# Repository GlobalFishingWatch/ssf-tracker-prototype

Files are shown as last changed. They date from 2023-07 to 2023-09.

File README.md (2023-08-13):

# ssf-tracker-prototype
Prototyping a low-cost low-power GPS tracker for small scale fishing vessels

## Project Goal
Develop a simple, robust, low cost hardware device that can be used for location tracking
for small-scale fishing vessels in a global context.

Pilot test the device and develop a plan to scale it out to >100k vessels.

GFW will develop cloud back end, web and app-based UX tools for interacting with the data, probably in house but potentially with a partner.

Data from the small vessels will be combined with other data GFW collects for larger vessels to provide a richer picture of what is happening.

[Project Background](background.md)

[Hardware requirements](requirements.md)

[Device Designs](design/README.md)

Diagrams in markdown files are formatted using [Mermaid](https://mermaid.js.org/)

## Developing

```console
git clone https://github.com/GlobalFishingWatch/ssf-tracker-prototype
cd ssf-tracker-prototype
```

See [README.md](controller/README.md) for more on developing the controller micropython code

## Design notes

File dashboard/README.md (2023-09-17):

# SSF Tracker Device Dashboard

This app connects to a local instance of the tracker device using Bluetooth LE (BLE).

This will only work in Chrome, and you need to enable BLE in Chrome before it will be able to connect.

To enable BLE in the browser, navigate to `chrome://flags/experimental-web-platform-features` and set it to `Enabled`

Then open index.html and you should be able to connect to the device and control it

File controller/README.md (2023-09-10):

# Micro Controller

The controller runs on an arduino ESP32 running micropython

## Set up the local dev environment
We use micropython to run the code in the arduino, nut we use standard python for development and testing because I haven't figured out how to use unittest properly in micropython.  Ideally we would run all the unitest in micropython on the dev machine so taht we know everything is the same as it will be on the arduino. 

### Python setup for osx - create a python environment if you don't aleady have one
```
conda create -n py311 python=3.11.4 
conda avtivate py311
```

### Create a python virtualenv
```console
pip install virtualenv
cd controller
virtualenv venv
source venv/bin/activate
pip install -r requirements-dev.txt 
```

### Run the unit tests
```console
python app/test.py
```

### install micropython on the ESP32-S3 board

Using [this guide](https://micropython.org/download/GENERIC_S3/)

```
pip install esptool

esptool.py --chip esp32-S3 --port /dev/tty.usbmodem101 erase_flash
esptool.py --chip esp32s3 --port /dev/tty.usbmodem101 write_flash -z 0 ~/Downloads/GENERIC_S3-20230426-v1.20.0.bin 
```

### Install micropython on the dev machine
On OSX, install micropython from source
https://docs.micropython.org/en/latest/develop/gettingstarted.html#building-the-unix-port-of-micropython

```console
git clone https://github.com/micropython/micropython
cd micropython/mpy-cross
make
cd ../ports/unix
make submodules
make
./micropython
```

Now install some packages from micropython-lib
```console
micropython -m mip install unittest
micropython -m mip install tempfile
micropython -m mip install logging
micropython -m mip install shutil
micropython -m mip install ujson
micropython -m mip install collecttions-deque
micropython -m mip install copy
```

Now you should be able to run the unit tests with micropython
```console
micropython app/test.py
```
 
### Install packages to the esp32 device
Use mpremote - [documentation](https://docs.micropython.org/en/latest/reference/mpremote.html)
```console
pip install mpremote

mpremote fs mkdir lib
mpremote mip install $(cat requirements-micropython-dev.txt)
```

### Copy files to the esp32 device
#### Copy with mpremote
```console
mpremote cp $(ls app/*.py) :
```
Note that this seems to fail intermittently, so here's an alternative way

#### Copy files with mpy-upload

Use mpy-upload - [documentation](https://github.com/nickzoic/mpy-utils)

First you need to find the port (mpremote finds it auto-magically)
```console
ls /dev/cu*
```

Then use the usb port to copy all the files
```console
pip install mpy-utils

mpy-upload --port /dev/cu.usbmodem5629254 app/*.py
```

### Open a REPL on the device so you can run things

```console
mpremote repl
```
You may need to hit ctrl-B to get a the `>>>` prompt

### Run the unit tests in the REPL
```python
>>> from test import run_all_tests_esp32
>>> run_all_tests_esp32()
```

### Now finally, run the App!
From the repl
```python
>>> import main
>>> main.app.run()
```
ctrl-c to break

## SOME RANDOM NOTES BELOW

How to create a virtual env using micropython (not working?)
```
ln -s /Users/paul/github/micropython/ports/unix/build-standard/micropython /usr/local/bin/micropython
micropython -m mip install venv
source venv-mpy/bin/activate 
```

### Using Thonny IDE to run python code on the ESP hardware

### Monitor the serial port directly from OSX

1. Connect the usb cable to the COM port (not the USB port)

2. find the device name
```
ls /dev/cu*
```
3. should look something like this
```
/dev/cu.usbmodem56292549741
```
4. then connect with screen
```
screen /dev/cu.usbmodem56292549741 115200
```
5. To exit screen, do ctrl-a and then k to kill the session

### set up mpy-utils for direct file system access
github: https://github.com/nickzoic/mpy-utils
```
pip install mpy-utils
```

Use mpremote
```console
pip install mpremote
```
To open a shell to the REPL. You may need to hit ctrl-B to get the prompt
```console
mpremote repl
```
It should auto-discover the usb port

To copy files from the host to the device
```console
mpremote cp test.py :tesy.py
mpremote cp test/*.py :
```

List files on the device
```console
mpremote fs ls
```

Install modules using mip onto the device
```console
mpremote fs mkdir lib
mpremote mip install logging
```

#### Copy files with mpy-upload
DEPRECATED - using `mpremote cp` is better

Use mpy-upload - [documentation](https://github.com/nickzoic/mpy-utils)

First you need to find the port (mpremote finds it auto-magically)
```console
ls /dev/cu*
```

Then use the usb port to copy all the files
```console
pip install mpy-utils

mpy-upload --port /dev/cu.usbmodem5629254 app/*.py
```

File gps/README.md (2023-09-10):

# GPS Testing

In prior experiments, we have found that the the biggest source of power use is getting a GPS fix.   

We want to try to measure how much power we will need to acquire GPS fixes over time

### Test Questions
1. How long on average does it take to get a GPS fix over a long series of wake/fix/sleep cycles
2. How much power do we consume while getting a fix
3. How do things change when we change the fix interval

### Test setup with the Adafruit Ultimate GPS
Using an arduino feather esp32 for the conroller and AdaFruit Ultimate GPS breakout 

### Test 1

* Power the GPS from the controller 3V3
* Install a button battery in the GPS
* Use the external antenna in an outdoor location with a clear view of the sky
* Set up a sleep/wake cycle in the controller, using deepsleep
* On sleep, disable the GPS with the `EN` pin
* On wake, enable the GPS, wait for it to get a fix
* After the GPS gets a fix, disable it with the `EN` in and send the controller to sleep

#### Measures
* Log the fixed location (so we can check consistency across multiple readings)
* Log the time from wake to fix
* Compute the average and cumulative time the controller spends awake
* Measure total power consumption of the entire system during wake and sleep
* Measure the power consumption of just the GPS with EN on and off

Run this test for a couple of days and see what the timings look like

#### Test 2

* Same setup as test 1, but try to put the controller into light sleep while you wait for the GPS to get a fix. 
* See if there is a way to wake the controller using the `FIX` pin perhaps?
* Or just sleep for a short period like 500ms and then wake and check
* Measure to see if this extra complexity reduces overall power consumption

#### Test 3

* Try using the built-in LOCUS logger in low power mode and let the controller deepsleep for a longer time, waking up to collect the logged positions once per hour

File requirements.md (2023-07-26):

# Device requirements

## Desired hardware characteristics

* Total 5-year cost of ownership < $500.  This includes
  * up front hardware cost
  * hardware replacement cost, depending on failure rate
  * data communications service
* Coverage: global between latitude -50 and +50
* Data collected: lat/lon, time, speed
* Data logging frequency: 5-10 miuntes
* Data transmission frequency: not longer than 4 hours, otherwise as often as power permits
* Hardware package:
  * As simple as possible.
  * Ideally it is permanently sealed - needs to stand up to rough treatment and maritme conditions
  * Only needs one indicator light
  * Wireless charging and configuration (BLE?)
  * Only needs one button (for activation & SOS)
  * Does not have to be pretty
* Power
  * Internal rechargeable battery
  * Can have solar power (but don't count on optimal placement for captureing solar.  Assume 10% of rated solar caapcity)
* Weight and size
  * Will be attached to the structure of the boat (probably with zip ties)
  * Can be heavy and bulky, but cannot have anything sticking out that can get broken off
* Trial locations
  * Indonesia (with GFW staff)
  * Philippines (with Rare staff)
* Intellectual property license
  * Generally, everything we do is open source, so fully open source hardware and software design would be great
  * GFW publishes all our software under Apache 2.0 and data under CC-BY-NC

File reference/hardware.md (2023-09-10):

# Hardware Reference

## Microcontrollers
### ESP32-S3 DevKit C
To flash, press and hold `reset` and `boot,` then release `reset` and the relase `boot`
Be sure also to connect to the `USB` usb-c port and not the `Com` port

#### Docs
* [Espressif](https://docs.espressif.com/projects/esp-idf/en/latest/esp32s3/hw-reference/esp32s3/user-guide-devkitc-1.html)
* [Amazon](https://www.amazon.com/gp/product/B0B6HT7V7P/ref=ppx_yo_dt_b_asin_title_o05_s00?ie=UTF8&psc=1)
* [Build and flash micropython](esp32-s3.md)

####Pinout
ESP32-S3 DevKit C-1 Pinout

### Arduino Nano 33 IoT
[Arduino Store Product Listing](https://store-usa.arduino.cc/products/arduino-nano-33-iot?selectedStore=us)

#### Pinout
Arduino Nano 33 IoT Pinout

## GPS modules
### Adafruit Ultimate GPS
* [Command reference](https://cdn-shop.adafruit.com/datasheets/PMTK%20command%20packet-Complete-C39-A01.pdf)
* [Pinout](https://learn.adafruit.com/adafruit-ultimate-gps/pinouts)
* [MT3339 Operation Manual](https://cdn-shop.adafruit.com/datasheets/GlobalTop%20MT3339%20PC%20Tool%20Operation%20Manual%20v1.1.pdf)
* [LOCUS logging user guide](https://cdn-shop.adafruit.com/datasheets/GTop%20LOCUS%20Library%20User%20Manual-v13.pdf)

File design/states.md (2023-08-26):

---
SSF Tracker State Transition Diagram
---
Abstract App states
```mermaid
flowchart TD
  boot([Start]) --> setup([Setup])
  setup -. timeout .-> sleep([Sleep])
  setup -- activity --> setup
  sleep -- double press --> setup
  sleep -. timer .-> log_gps([Log GPS])
  log_gps --> sleep
  log_gps -- buffer full --> transmit([Transmit])
  transmit --> sleep
  sleep -- short press --> status([Status])
  status -. timeout .-> sleep
  sleep -- long press --> warn_sos([Warn SOS])
  warn_sos -. timeout .-> sos([SOS])
  warn_sos -- long press --> sleep
  sos -- long press --> sleep
```

Main App State Diagram
```mermaid
stateDiagram-v2 
  Boot --> Idle : reset
  Idle --> LogGPS: gps_timer
  LogGPS --> LogGPS: gps_ready
  LogGPS --> Transmit: buffer_full
  LogGPS --> Idle: buffer_not_full
  LogGPS --> Idle: gps_fail
  Transmit --> Idle: transmit_success
  Transmit --> Idle : transmit_fail
  Idle --> Sleep: idle_timeout
  Sleep --> Idle: timer_wake
  Sleep --> Idle: button_wake
  Idle --> Setup: btn_short_press
  Setup --> Idle: setup_timeout
  Setup --> Setup: ble_activity
  Idle --> WarnSOS: btn_long_press
  WarnSOS --> Idle: btn_press
  WarnSOS --> SOS: sos_timeoue
  SOS --> Idle: btn_long_press
  
```

GPS Subsystem
```mermaid
stateDiagram-v2 
    Sleep --> Locating: locate
    Locating --> Ready: gps_ready
    Locating --> Failed: timeout
    note right of Failed : signal gps_fail
    Failed --> Locating: reset
    Ready --> Locating: reset
    Locating --> Sleep: sleep
    Ready --> Sleep: sleep
    note right of Ready : signal gps_ready

```

SatCom Subsystem
```mermaid
stateDiagram-v2 
    Sleep --> Sending: send
    Sending --> Success: message_sent
    note right of Success : signal transmit_success
    Sending --> Fail: timeout
    note right of Fail : signal transmit_fail
    Success --> Sleep: reset
    Fail --> Sleep: reset
```

Button Subsystem
```mermaid
stateDiagram-v2
  Released --> Pressing : btn_down
  Pressing --> Released : btn_up
  Pressing --> Pressed : debounce_timeout
  note right of Pressed : signal btn_short_press, btn_long_press
  Pressed --> Releasing : btn_up
  Releasing --> Pressed : btn_down
  Releasing --> Released : debounce_timeout   
  note left of Released : signal btn_released
  Pressed --> Pressed : long_press_timeout
```

Indicator Subsystem
```mermaid
stateDiagram-v2
  LED_On --> LED_Off : blink_timeout
  LED_Off --> LED_On : blink_timeout
```

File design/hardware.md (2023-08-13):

---
SSF Tracker Hardware Abstraction Diagram
---

```mermaid
flowchart TD
    arduino[[Arduino]] --- gps[[GPS]]
    gps --- gps_ant{GPS Ant}
    arduino --- sat_modem[[Sat Modem]]
    sat_modem --- sat_ant{Sat Ant}
    arduino --- led((LED))
    arduino --- button[/Button\]
    buck_boost(Buck/Boost) -- 3.3v --- arduino
    charge_ctrl(Charge Ctrl) --- buck_boost
    charge_ctrl --- battery[(Battery)]
    charge_ctrl -- SOC --- arduino
    charge_coil((Charge Coil)) --- charge_ctrl
```

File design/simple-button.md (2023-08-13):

---
A state diagram for a simple button debounce
---

```mermaid
stateDiagram-v2
  Released --> Pressing : btn_down
  Pressing --> Released : btn_up
  Pressing --> Pressed : timeout
  Pressed --> Releasing : btn_up
  Releasing --> Pressed : btn_down
  Releasing --> Released : timeout   
```

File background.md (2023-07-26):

# Purpose and background

There are about 3 million small fishing vessels (generally less that 12m length, operating out of fishing villages across the global south, especially Indonesia, Philippines and West Africa.

Small scale fishing is responsible for about half of the global catch globally. Unsustainalbe over-fishing and encroachment from large scale industrial fishing threatens livelihoods of the small scale fishers and the communities that depend on them.

Many NGOs and government programs are woking to make management of these fisheries more sustainable with diverse strategies.

One thing that most of the management plans have in common is the need to better understand where and when fishing is happening, and provide mechanism to detect rules violations such as fishing in off limits areas, out of season and exceeding quotas.

This is generally accomplished through some sort of opt-in location tracking of the fishing vessels, often with a system for transparency so that all participants can see their own tracking data as well as all the other members of the fishery.

GFW has ben experimenting in Indonesia with various tracking hardware and software systems, and to date we have not found any off the shelf solution that can scale effectively.

Most trials by orgs like GFW will deploy 10, 100 or occasionally up to 1000 devices, but none have managed to find a system that can scale to the 100K+ level that is needed.

The primary barriers to wider adoption are
* Cost for hardware and associated data communications service
* Hardware reliability
* Data communication when the vessel is far from shore

All devices we have tried that meet performance needs are too expensive to be sustainable long term without subsidies from non-profits (the primary source) or government.   We are looking for a solution that can be sustained by the commercial activirty of the fishery where it is used, which means that the total system cost needs to be less than the incremental value that the system produces witin the fishery on a per-vessel basis.

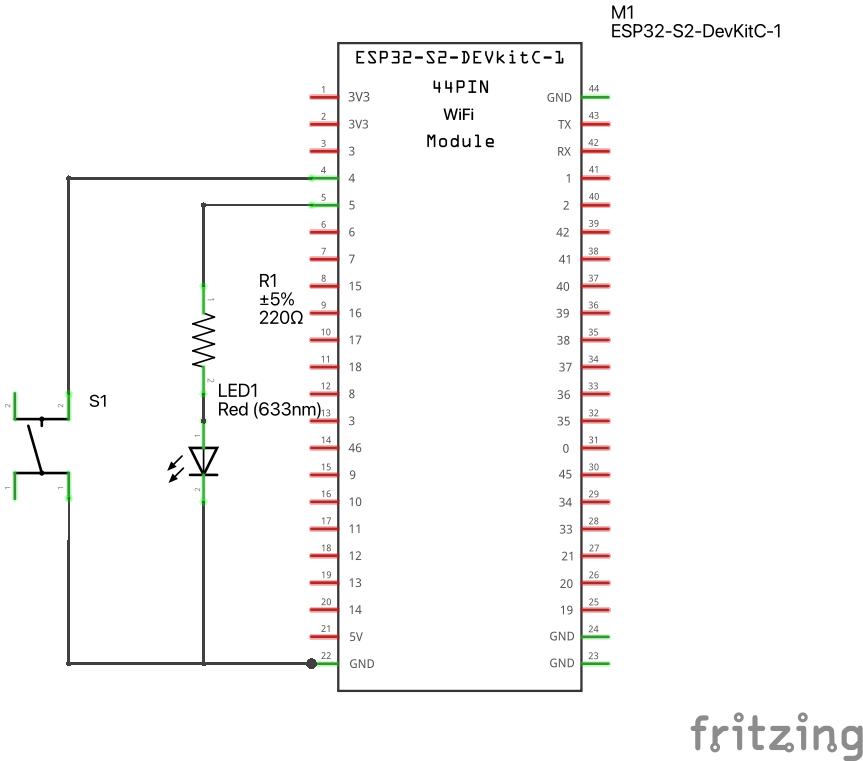
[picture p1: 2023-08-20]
design/simple_button_schematic.png

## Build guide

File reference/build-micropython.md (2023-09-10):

## Building micropython for ESP32 S3

### Targeting the ESP32-S3 DevKit C board (Paul's board)

Starting here:

https://docs.espressif.com/projects/esp-idf/en/latest/esp32/get-started/index.html#installation-step-by-step
```
brew install cmake ninja dfu-util
/usr/sbin/softwareupdate --install-rosetta --agree-to-license
mkdir -p ~/esp
cd ~/esp
git clone -b v5.0.2 --recursive https://github.com/espressif/esp-idf.git esp-idf-v5.0.2
ln -s esp-idf-v5.0.2 esp-idf    
cd esp-idf-v5.0.2/
./install.sh esp32,esp32s3
. $HOME/esp/esp-idf-v5.0.2/export.sh
```
Now build the esp32 micropython binary
```console
cd micropython/ports/esp32
make clean
make submodules
make BOARD=GENERIC_S3
```

To flash it to the ESP32, get the port and MAKE SURE the device is in the bootloader state
```commandline
ls /dev/cu*
```
Now write to flash
```console
python \
~/esp/esp-idf-v5.0.2/components/esptool_py/esptool/esptool.py \
-p /dev/cu.usbmodem1101 \
-b 460800 \
--before default_reset \
--after no_reset \
--chip esp32s3  \
write_flash \
--flash_mode dio \
--flash_size 8MB \
--flash_freq 80m \
0x0 build-GENERIC_S3/bootloader/bootloader.bin \
0x8000 build-GENERIC_S3/partition_table/partition-table.bin \
0x10000 build-GENERIC_S3/micropython.bin
 ```

### Targeting OSX

On OSX, install micropython from source
https://docs.micropython.org/en/latest/develop/gettingstarted.html#building-the-unix-port-of-micropython

```console
git clone https://github.com/micropython/micropython
cd micropython/mpy-cross
make
cd ../ports/unix
make submodules
make
./micropython
```

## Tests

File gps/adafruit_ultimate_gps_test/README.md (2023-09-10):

# Test scenarios for low power GPS logging using micropython 

Board: ESP32-S3 DevKit C with micropython installed
GPS module: Adafruit Ultimate GPS

## Wiring

* Connect GPS `TX` and `RX`to pins 9 and 10
* GPS power from `3V3`
* CR2032 battery installed
* `EN` Pin from GPS to GPIO output pin 8

## Test Cases

### Test 1: Verify setup
  * Connect to the GPS and make sure that it can fix a location

### Test 2: Turn the GPS on and off 
  * Turn the GPS on and off with the EN pin

### Test 3: Measure warm start
  * Measure time to warm start after GPS is off for 1, 2, 5, 10 minutes

### Test 4: Measure cold start
  * Measure time to cold start after GPS is off for > 4 hours

### Test 5: LOCUS logging
  * See if backup mode really only uses 7ua while sleeping

### Test notes

#### Test setup
I used my digital multimeter to measure current draw from the gps module.  I connect it in series on the high side. 
At first I was powering the gps fro the `3V3` pin on the microcontroller, but when I put the multimeter in between 
them the gps starting spitting out garbage on the serial line, so I switched it to power the GPS separately with 4V
from my desktop power supply (making sure to have a common ground!)

After running the gps through all the different modes, I measured the following  

### Power use
| Mode | Current | Notes |
| ---- | --- | ----- |
| Active | ~30ma | variable because of the flashing LED |
| EN pin low | 300 ua | |
| Standby mode | 1.65 ma | the sleep cycle using periodic standby mode |
| Backup mode | 1.65 ma | the sleep cycle using periodic backup mode |
| VBATT | 7 ua | Hard to measure, but this is what the spec says and seems to be accurate |

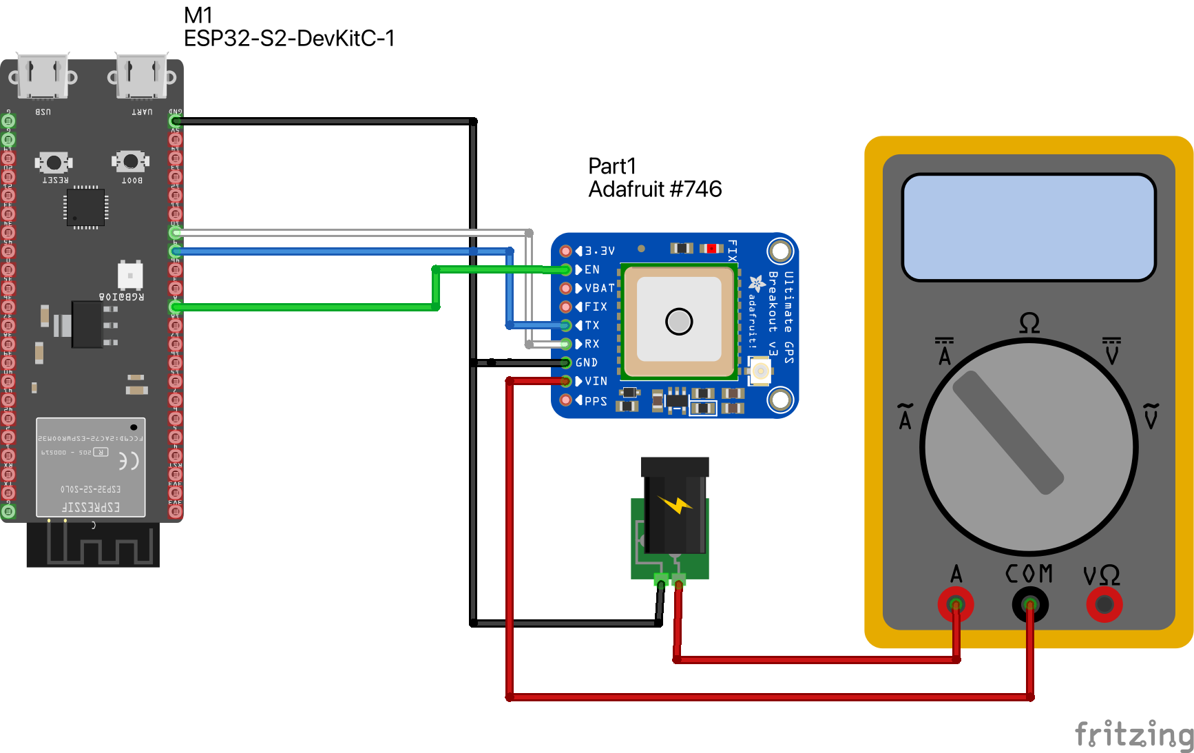
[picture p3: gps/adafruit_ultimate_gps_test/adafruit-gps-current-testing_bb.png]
Wiring Diagram

Notes
* I pulled the EN pin low using a GPIO pin and by just connecting it to ground.  Both methods gave teh same result

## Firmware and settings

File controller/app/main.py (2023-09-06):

# main.py
# this is the main app for the microcontroller
# runs after boot.py



# from config import load_config
# from config import configure_logger

# from app import App
# from wiring_esp32 import WiringESP32
#
# app_config = {
#
# }
# app = App.from_settings('./config.json', wiring_type=WiringESP32)
# app.initialize()

# # LOAD CONFIG
# config_filename = './config.json'
# app_config = load_config(config_filename)
#
# # SET UP LOGGING
# log = configure_logger(app_config)
# log.info('Starting App...')

# app = App(WiringESP32, log=log, config=app_config)
# app.initialize()
# app.run()


import machine
import esp32
from machine import deepsleep
from machine import lightsleep
from micropython import schedule

from machine import Pin
from time import sleep


def wake_msg():
    reset_cause = machine.reset_cause()
    if reset_cause is machine.HARD_RESET:
        reset_cause = 'HARD_RESET'
    elif reset_cause is machine.PWRON_RESET:
        reset_cause = 'PWRON_RESET'
    elif reset_cause is machine.WDT_RESET:
        reset_cause = 'WDT_RESET'
    elif reset_cause is machine.DEEPSLEEP_RESET:
        reset_cause = 'DEEPSLEEP_RESET'
    elif reset_cause is machine.SOFT_RESET:
        reset_cause = 'SOFT_RESET'

    wake_reason = machine.wake_reason()
    if wake_reason is machine.PIN_WAKE:
        wake_reason = 'PIN_WAKE'
    elif wake_reason is machine.EXT0_WAKE:
        wake_reason = 'EXT0_WAKE'
    elif wake_reason is machine.EXT1_WAKE:
        wake_reason = 'EXT1_WAKE'
    elif wake_reason is machine.TIMER_WAKE:
        wake_reason = 'TIMER_WAKE'
    elif wake_reason is machine.TOUCHPAD_WAKE:
        wake_reason = 'TOUCHPAD_WAKE'
    elif wake_reason is machine.ULP_WAKE:
        wake_reason = 'ULP_WAKE'
    return reset_cause,wake_reason


def irq_scheduled(pin):
    log.info(f'irq {pin.value()}')

def irq_handler(pin):
    schedule(irq_scheduled, pin)


led = Pin (5, Pin.OUT)
wake1 = Pin(4, mode = Pin.IN)
# wake1.irq(handler=irq_handler, trigger=Pin.IRQ_RISING | Pin.IRQ_FALLING, wake=machine.SLEEP)
esp32.wake_on_ext0(pin = wake1, level = esp32.WAKEUP_ANY_HIGH)

def run_test_deep_sleep():
    log.info(wake_msg())
    #blink LED
    led.value(1)
    sleep(0.5)
    led.value(0)
    sleep(0.5)

    # wait 5 seconds so that you can catch the ESP awake to establish a serial communication later
    # you should remove this sleep line in your final script
    sleep(2)

    log.info('Going into deep sleep...')
    sleep(1)

    #sleep for 10 seconds (10000 milliseconds)
    deepsleep(10000)


def run_test_light_sleep():
    while True:
        log.info(wake_msg())
        #blink LED
        led.value(1)
        sleep(0.5)
        led.value(0)
        sleep(0.5)

        # wait 2 seconds so that you can catch the ESP awake to establish a serial communication later
        # you should remove this sleep line in your final script
        sleep(2)

        log.info('Going into light sleep...')
        sleep(1)

        #sleep for 10 seconds (10000 milliseconds)
        # irq_state = machine.disable_irq()
        # wake1.irq(handler=None)
        lightsleep(10000)
        # wake1.irq(handler=irq_handler)
        # machine.enable_irq(irq_state)

def run_test_sleep():
    while True:
        log.info(wake_msg())
        #blink LED
        led.value(1)
        sleep(0.5)
        led.value(0)
        sleep(0.5)

        # wait 2 seconds so that you can catch the ESP awake to establish a serial communication later
        # you should remove this sleep line in your final script
        sleep(2)

        log.info('Going into sleep...')

        #sleep for 10 seconds (10000 milliseconds)
        sleep(10)

def blink():
    while True:
        led.value(not led.value())
        sleep(0.5)

# run_test_deep_sleep()
# run_test_light_sleep()
# run_test_sleep()
# blink()

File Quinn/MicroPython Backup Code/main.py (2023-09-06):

# This file is executed on every boot (including wake-boot from deepsleep)
#import esp
#esp.osdebug(None)
#import webrepl
#webrepl.start()

import machine
import esp32
import neopixel
from util import RGB
import time
from satellite import Satellite
from gps import GPS
from util import log
from machine import deepsleep
from micropython import schedule
import json
import boot


# Function to handle setup mode
def setup_mode():
    color.setColor("green")
    time.sleep(3)
    color.setColor("off")
    
# Function to handle SOS mode
def sos():
    for x in range(5):
        color.setColor("red")
        time.sleep(1)
        color.setColor("off")

def main():
    print(wake_msg())
    
    color.setColor("white")
    time.sleep(2)
    color.setColor("off")
    
    # Load config
    # default values
    config = {'gps_timeout': 10}
    
    # Create an instance of the Satellite and GPS class
    sat = Satellite()
    gps = GPS(8, 7, 38400, config)

    cfg_filename = 'lib/config2.json'
    try:
        # try to load the file
        with open(cfg_filename, 'r') as cfg_file:
            config.update(json.load(cfg_file))
    except OSError:
        # file doesn't exist, so create it
        with open(cfg_filename, 'w') as cfg_file:
              json.dump(config, cfg_file)

    # Determine wakeup reason
    # If reason is sos button, enter SOS mode
    # If reason is setup button, enter setup
    '''
    triggered_alarm = alarm.wake_alarm
    if triggered_alarm != None and triggered_alarm.pin:
        if triggered_alarm.pin == sos_pin_alarm:
            log()
        elif triggered_alarm.pin == setup_pin_alarm:
            setup_mode()
    '''

    color.setColor("off")
    gps.logLocation()
    print("Location Logged")
    print(gps.count_lines())

    if gps.count_lines() >= max_lines:
        print(gps.count_lines())
        #setColor("yellow")
        #time.sleep(5)
        sat.send_log(gps.readLocations())
        gps.delete_log_file()


    # Indicate machine is going to sleep and sleep(in milliseconds)
    # https://randomnerdtutorials.com/micropython-esp32-deep-sleep-wake-up-sources/
    color.setColor("red")
    time.sleep(.2)
    color.setColor("blue")
    #Set sleep alarm

    #write out the config file before we go to sleep
    with open(cfg_filename, 'w') as cfg_file:
        json.dump(config, cfg_file)
        
    #Deep sleep for x/1000 seconds
    #alarm.exit_and_deep_sleep_until_alarms(time_alarm, sos_pin_alarm, setup_pin_alarm)
    deepsleep(5000)
    
    
try:
    main()
except OSError:
    log("OS Error")

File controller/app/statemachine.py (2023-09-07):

# A basic state machine
from util import default_logger
from collections import deque


class State(object):
    def __init__(self, name, on_enter=None, on_exit=None):
        self.name = name
        self.on_enter = on_enter
        self.on_exit = on_exit

    def enter(self, event_data):
        event_data.machine.callback(self.on_enter, event_data)

    def exit(self, event_data):
        event_data.machine.callback(self.on_exit, event_data)


class Event(object):
    # NB: there is a built-in deque in some micropython builds that takes 2 positional params
    # If you get an error here, then you want to make sure you are using collections-deque from micropython-lib
    event_queue = deque()


    def __init__(self, name, machine, **kwargs):
        self.name = name
        self.machine = machine
        self.kwargs = kwargs

    def _trigger(self):
        # Trigger the event on the statemachine immediately
        self.machine.trigger_event(self)

    def trigger(self):
        # does the same thing as schedule
        self.schedule()

    def schedule(self):
        # put the event in the event queue to be executed on the next call to trigger_scheduled_events()
        self.event_queue.append(self)

    @classmethod
    def trigger_scheduled_events(cls):
        while cls.event_queue:
            event = cls.event_queue.popleft()
            event._trigger()


class MockEvent(Event):
    # Event class for testing.  Does not do anything other than count the
    # number of times that the event has benn triggered
    def __init__(self, name, **kwargs):
        self.trigger_count = 0
        super(MockEvent, self).__init__(name=name, machine=None, **kwargs)

    def _trigger(self):
        pass

    def schedule(self):
        self.trigger_count += 1


class Transition(object):
    def __init__(self, event, source=None, dest=None, before=None, after=None, condition=None):
        self.source = source
        self.dest = dest
        self.event = event.name if isinstance(event, Event) else event
        self.before = before
        self.after = after
        self.condition = condition

    def eval_condition(self, event):
        if self.condition:
            return event.machine.callback(self.condition, event)
        return True

    def execute(self, event):
        machine = event.machine

        if self.eval_condition(event):
            machine.callback(self.before, event)
            if self.source:
                machine.callback(machine.get_state(self.source).on_exit, event)
            if self.dest:
                machine.set_state(self.dest)
                machine.callback(machine.get_state(self.dest).on_enter, event)
            machine.callback(self.after, event)


class StateMachine(object):
    machines = {}

    @classmethod
    def generate_unique_name(cls, basename):
        for n in range(1, 10):
            name = f'{basename}{n}'
            if name not in cls.machines:
                break

        return name

    @classmethod
    def get_machine(cls, machine_name):
        return cls.machines[machine_name]

    def __init__(self, states=None, transitions=None, initial_state=None, name=None, log=None):
        self.name = name if name else self.generate_unique_name(self.__class__.__name__)
        if self.name in self.machines:
            raise ValueError(f'Statemachine name "{self.name}" is not unique')
        self.machines[self.name] = self

        self.log = log if log else default_logger()
        self.states = {}
        self._state = None
        self._transitions = transitions if transitions else []

        if states:
            self.add_states(states)

        # set the initial state
        # if no valid initial state is provided, use the fist state in the list
        if not initial_state and states:
            initial_state = states[0]
        self._state = self.get_state(initial_state)

    @property
    def state(self):
        return self._state

    def get_state(self, state):
        if isinstance(state, State):
            return state
        else:
            return self.states[state]

    def set_state(self, state):
        if not isinstance(state, State):
            state = self.get_state(state)
        self.log.debug(f'{self.name}: {self._state.name} => {state.name}')
        self._state = state

    def get_event(self, event, **kwargs):
        self.get_event_transitions(event)  # will raise exception if there are no matching transitions
        if isinstance(event, Event):
            event.machine = self
            event.kwargs.update(kwargs)
        else:
            event = Event(name=event, machine=self, **kwargs)
        return event

    # get all transitions that are triggered by this event
    def get_event_transitions(self, event):
        if isinstance(event, Event):
            event = event.name
        event_transitions = [t for t in self._transitions if t.event == event]
        if not event_transitions:
            raise ValueError(f'State machine "{self.name}" does not have any transitions with event "{event}"')
        return event_transitions

    # get all transitions triggered but the given event that have the source state matching the
    # current machine state
    def get_matched_transitions(self, event, state):
        state = self.get_state(state)
        if isinstance(event, Event):
            event = event.name
        event_transitions = self.get_event_transitions(event)
        return [t for t in event_transitions if t.source is None or self.get_state(t.source) == state]

    def add_states(self, states):
        for s in states:
            if isinstance(s, State):
                self.states[s.name] = s
            else:
                self.states[s] = State(name=s)

    def trigger_event(self, event, **kwargs):
        event = self.get_event(event, **kwargs)
        self.log.debug(f'{self.name}: event {event.name}')
        transitions = self.get_matched_transitions(event=event, state=self.state)
        for t in transitions:
            t.execute(event)

    def schedule_event(self, event, **kwargs):
        event = self.get_event(event, **kwargs)
        event.schedule()

    @classmethod
    def callback(cls, func, event):
        func = getattr(event.machine, func) if func else None
        return func(event) if func else None

    def save_state(self):
        return dict(
            state=self._state.name
        )

    def load_state(self, state):
        self._state = self.get_state(state['state'])

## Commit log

2023-08-13 Set up framework for the micropytho contoller app
2023-08-20 Complete basic app working
    [simple_button_schematic.fzz]
2023-08-21 replace json with ujson
    [config.py, test_config.py]
2023-09-02 wire up the Mock GPS subsystem
2023-09-03 Test plan for GPS power consumption
2023-09-05 add RGB support in wiring. Fix unit tests
    [config.py, main.py, statemachine.py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]
2023-09-06 small refactoring in wiring
2023-09-10 test note for gps power use
    [adafruit-gps-current-testing.fzz]
2023-09-23 get gps working in esp32 wiring
